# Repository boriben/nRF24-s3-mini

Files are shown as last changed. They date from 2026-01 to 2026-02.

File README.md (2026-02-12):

## ESP32-S3-mini + Ebyte nRF24 multi-purpose controller PCB 
### Features/components:
- ESP32-S3-mini-1U connected via SPI to Ebyte E01 2G4M27SX (nRF24) 
- Power from USB-C or lithium battery
- BQ2409 lithium battery charger IC with switch to toggle between 1A and 257mA fast-charge rate
- Resistor divider to monitor battery level
- Buck-boost converter to maintain 3.3V output across battery life
- Joystick, buttons, extra GPIOs for UART, I2C OLED, power, etc.
- flash ESP32 via USB-C



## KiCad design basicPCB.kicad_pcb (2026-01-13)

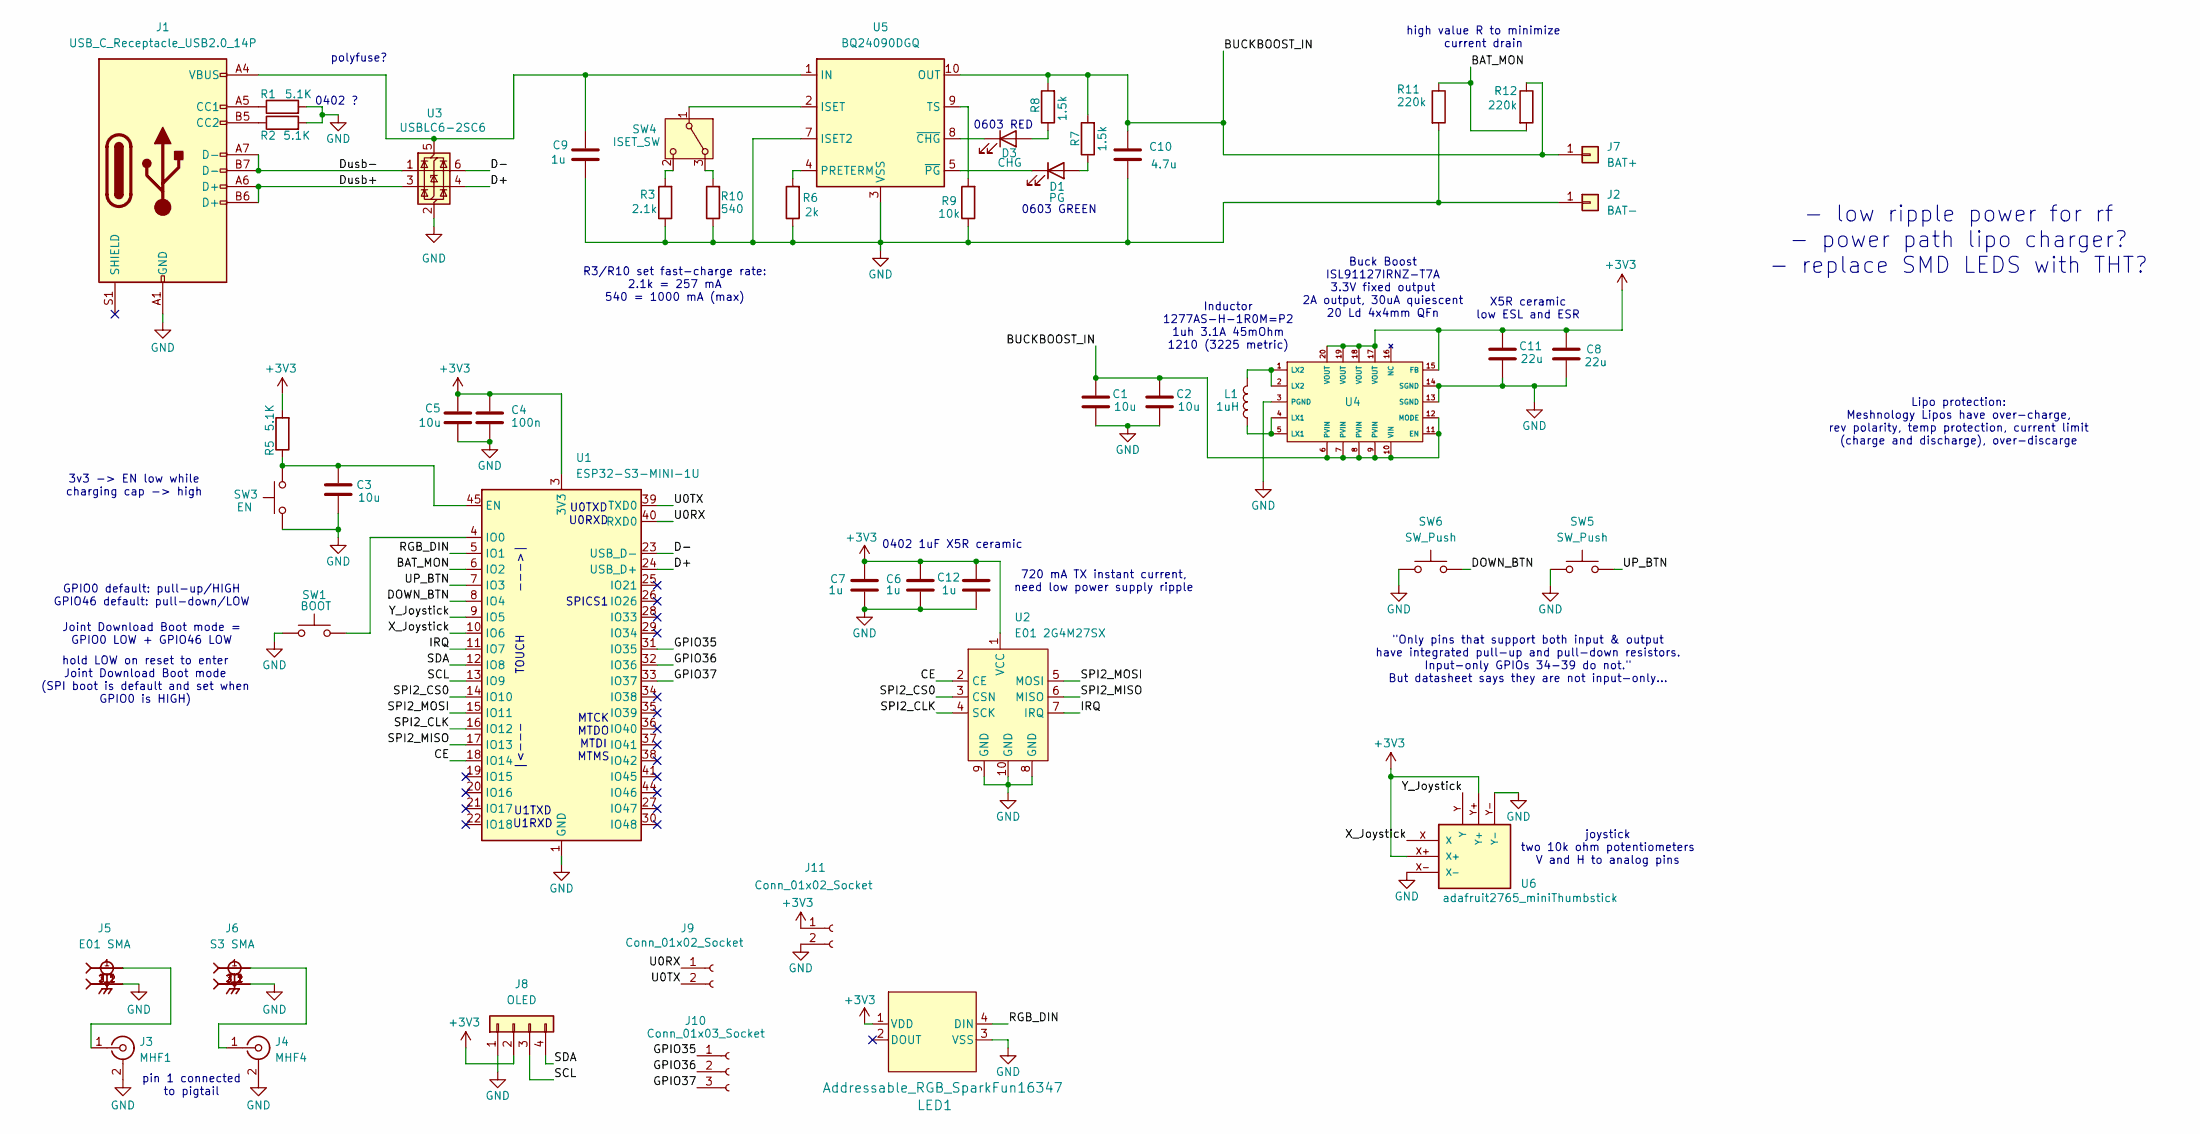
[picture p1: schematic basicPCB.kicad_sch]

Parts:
C1, C2: 10u; C_0603_1608Metric
C3, C5: 10u; C_0402_1005Metric
C4: 100n; C_0402_1005Metric
C6, C7, C9, C12: 1u; C_0402_1005Metric
C8, C11: 22u; C_0603_1608Metric
C10: 4.7u; C_0402_1005Metric
D1: PG; LED_0603_1608Metric
D3: CHG; LED_0603_1608Metric
J1: USB_C_Receptacle_USB2.0_14P; USB_C_Receptacle_G-Switch_GT-USB-7010ASV
J2: BAT-; PinHeader_1x01_P2.54mm_Vertical
J3: MHF1; U.FL_Molex_MCRF_73412-0110_Vertical
J4: MHF4; IPEX_20449-001E-03
J5: E01 SMA; SAMTEC_SMA-J-P-H-ST-EM1; PARTREV G
J6: S3 SMA; SAMTEC_SMA-J-P-H-ST-EM1; PARTREV G
J7: BAT+; PinHeader_1x01_P2.54mm_Vertical
J8: OLED; PinHeader_1x04_P2.54mm_Vertical
J9, J11: Conn_01x02_Socket; PinHeader_1x02_P2.54mm_Vertical
J10: Conn_01x03_Socket; PinHeader_1x03_P2.54mm_Vertical
L1: 1uH; 1277AS-H-1R0M=P2
LED1: Addressable_RGB_SparkFun16347; SparkFun_16347_AddressableRGB
R1, R2, R5: 5.1K; R_0402_1005Metric
R3: 2.1k; R_0402_1005Metric
R6: 2k; R_0402_1005Metric
R7, R8: 1.5k; R_0402_1005Metric
R9: 10k; R_0402_1005Metric
R10: 540; R_0402_1005Metric
R11, R12: 220k; R_0402_1005Metric
SW1: BOOT; 3x4x2mm button
SW3: EN; 3x4x2mm button
SW4: ISET_SW; SW_Slide-03_Wuerth-WS-SLTV_10x2.5x6.4_P2.54mm
SW5, SW6: SW_Push; SW_PUSH-12mm
U1: ESP32-S3-MINI-1U; ESP32-S2-MINI-1U
U2: E01 2G4M27SX; Ebyte E01 2G4M27SX
U3: USBLC6-2SC6; SOT-23-6
U4: QFN-20-1EP_4x4mm_P0.5mm_EP2.5x2.5mm
U5: BQ24090DGQ; HVSSOP-10-1EP_3x3mm_P0.5mm_EP1.57x1.88mm_ThermalVias
U6: adafruit2765_miniThumbstick; PARTREV N/A

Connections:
+3V3: C4.1, C5.1, C6.1, C7.1, C8.1, C11.1, C12.1, J8.2, J11.1, LED1.1 (VDD), R5.2, U1.3 (3V3), U2.1 (VCC), U4.15 (FB), U4.17 (VOUT), U4.18 (VOUT), U4.19 (VOUT), U4.20 (VOUT), U6.X+, U6.Y+
/BAT_MON: R11.1, R12.2, U1.6 (IO2)
/BUCKBOOST_IN: C1.1, C2.1, C10.1, J7.1, R7.2, R8.2, R12.1, U4.6 (PVIN), U4.7 (PVIN), U4.8 (PVIN), U4.9 (PVIN), U4.10 (VIN), U4.11 (EN), U4.12 (MODE), U5.10 (OUT)
/CE: U1.18 (IO14), U2.2 (CE)
/D+: U1.24 (USB_D+), U3.4 (I/O2)
/D-: U1.23 (USB_D-), U3.6 (I/O1)
/DOWN_BTN: SW6.2, U1.8 (IO4)
/Dusb+: J1.A6 (D+), J1.B6 (D+), U3.3 (I/O2)
/Dusb-: J1.A7 (D-), J1.B7 (D-), U3.1 (I/O1)
/GPIO35: J10.1, U1.31 (IO35)
/GPIO36: J10.2, U1.32 (IO36)
/GPIO37: J10.3, U1.33 (IO37)
/IRQ: U1.11 (IO7), U2.7 (IRQ)
/RGB_DIN: LED1.4 (DIN), U1.5 (IO1)
/SCL: J8.3, U1.13 (IO9)
/SDA: J8.4, U1.12 (IO8)
/SPI2_CLK: U1.16 (IO12), U2.4 (SCK)
/SPI2_CS0: U1.14 (IO10), U2.3 (CSN)
/SPI2_MISO: U1.17 (IO13), U2.6 (MISO)
/SPI2_MOSI: U1.15 (IO11), U2.5 (MOSI)
/U0RX: J9.1, U1.40 (RXD0)
/U0TX: J9.2, U1.39 (TXD0)
/UP_BTN: SW5.2, U1.7 (IO3)
/X_Joystick: U1.10 (IO6), U6.X
/Y_Joystick: U1.9 (IO5), U6.Y
GND: C1.2, C2.2, C3.2, C4.2, C5.2, C6.2, C7.2, C8.2, C9.2, C10.2, C11.2, C12.2, J1.A1 (GND), J1.A12 (GND), J1.B1 (GND), J1.B12 (GND), J2.1, J3.2 (Ext), J4.2 (Ext), J5.2_1, J5.2_2, J5.3_1, J5.3_2, J6.2_1, J6.2_2, J6.3_1, J6.3_2, J8.1, J11.2, LED1.3 (VSS), R1.2, R2.2, R3.1, R6.1, R9.1, R10.1, R11.2, SW1.1, SW3.1, SW5.1, SW6.1, U1.1 (GND), U1.2 (GND), U1.42 (GND), U1.43 (GND), U1.46 (GND), U1.47 (GND), U1.48 (GND), U1.49 (GND), U1.50 (GND), U1.51 (GND), U1.52 (GND), U1.53 (GND), U1.54 (GND), U1.55 (GND), U1.56 (GND), U1.57 (GND), U1.58 (GND), U1.59 (GND), U1.60 (GND), U1.61 (GND), U1.62 (GND), U1.63 (GND), U1.64 (GND), U1.65 (GND), U2.8 (GND), U2.9 (GND), U2.10 (GND), U3.2 (GND), U4.3 (PGND), U4.13 (SGND), U4.14 (SGND), U5.3 (VSS), U5.7 (ISET2), U5.11 (VSS), U6.X-, U6.Y-
unnamed: D1.2 (A), R7.1
unnamed: D1.1 (K), U5.5 (~PG)
unnamed: D3.2 (A), R8.1
unnamed: D3.1 (K), U5.8 (~CHG)
unnamed: J1.A5 (CC1), R1.1
unnamed: J1.B5 (CC2), R2.1
unnamed: J3.1 (In), J5.1
unnamed: J4.1 (In), J6.1
unnamed: L1.1, U4.4 (LX1), U4.5 (LX1)
unnamed: L1.2, U4.1 (LX2), U4.2 (LX2)
unnamed: R10.2, SW4.3 (A)
unnamed: SW4.1 (B), U5.2 (ISET)
unnamed: R3.2, SW4.2 (C)
unnamed: C3.1, R5.1, SW3.2, U1.45 (EN)
unnamed: SW1.2, U1.4 (IO0)
unnamed: C9.1, J1.A4 (VBUS), J1.A9 (VBUS), J1.B4 (VBUS), J1.B9 (VBUS), U3.5 (VBUS), U5.1 (IN)
unnamed: R6.2, U5.4 (PRETERM)
unnamed: R9.2, U5.9 (TS)

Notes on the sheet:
Buck Boost ISL91127IRNZ-T7A 3.3V fixed output 2A output, 30uA quiescent 20 Ld 4x4mm QFn
polyfuse?
|<--- TOUCH --->|
3v3 -> EN low while charging cap -> high
high value R to minimize current drain
X5R ceramic low ESL and ESR
U0TXD U0RXD
joystick two 10k ohm potentiometers V and H to analog pins
U1TXD U1RXD
"Only pins that support both input & output have integrated pull-up and pull-down resistors. Input-only GPIOs 34-39 do not." But datasheet says they are not input-only...
720 mA TX instant current, need low power supply ripple
SPICS1
Lipo protection: Meshnology Lipos have over-charge, rev polarity, temp protection, current limit (charge and discharge), over-discarge
- low ripple power for rf - power path lipo charger? - replace SMD LEDS with THT?
hold LOW on reset to enter Joint Download Boot mode (SPI boot is default and set when GPIO0 is HIGH)
R3/R10 set fast-charge rate: 2.1k = 257 mA 540 = 1000 mA (max)
0402 ?
0402 1uF X5R ceramic
Inductor 1277AS-H-1R0M=P2 1uh 3.1A 45mOhm 1210 (3225 metric)
0603 GREEN
pin 1 connected to pigtail
GPIO0 default: pull-up/HIGH GPIO46 default: pull-down/LOW Joint Download Boot mode = GPIO0 LOW + GPIO46 LOW
0603 RED
MTCK MTDO MTDI MTMS

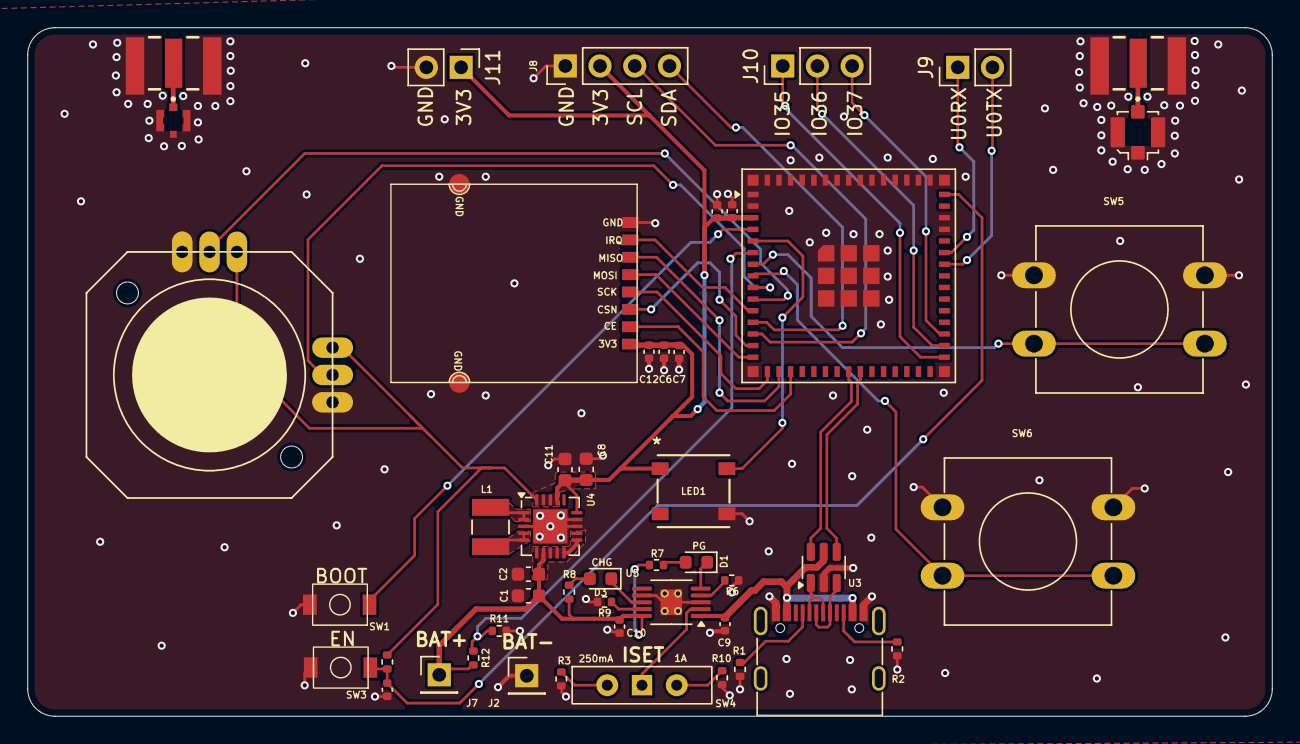
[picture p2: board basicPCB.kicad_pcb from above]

Board: 4 copper layers, 91.0 x 50.4 mm, 49 parts (0 on the bottom side), 44 nets.
